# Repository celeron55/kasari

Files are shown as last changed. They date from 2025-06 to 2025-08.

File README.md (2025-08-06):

# Kasarisw: Spinning Robot with LIDAR Navigation

## Overview
This project features a spinning robot using a repurposed LDS02RR LIDAR (fixed
mount, fake encoder for max sampling) to enable autonomous navigation and
object following/wall avoidance. The robot spins its body (500-2000 RPM),
measures rotation via ADXL373 accelerometer, and achieves directional movement
through differential motor RPM modulation.

See `kasarisw/README.md` for information about the software.

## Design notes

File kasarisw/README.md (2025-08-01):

# Kasarisw: Spinning Robot with LIDAR Navigation

## Overview
This project features a spinning robot using a repurposed LDS02RR LIDAR (fixed
mount, fake encoder for max sampling) to enable autonomous navigation and
object following/wall avoidance. The robot spins its body (500-2000 RPM),
measures rotation via ADXL373 accelerometer, and achieves directional movement
through differential motor RPM modulation.

- **Firmware**: ESP32-based, handles sensors, motion planning, WiFi event streaming (binary over TCP).
- **Simulator**: PC GUI (egui) for log replay or virtual world simulation; visualizes LIDAR points, detections, behavior and collisions.
- **Shared Logic**: LIDAR/accel processing, binning (90 bins, 4° each), object detection (walls/objects via averages/dips).
- **Python GUI**: `event_monitor.py` for real-time monitoring, logging (JSON), controls over TCP.
- **Goals**: Compare real vs. simulated behavior; optimize non-standard LIDAR setup.

The robot maintains two rotations: physical (LIDAR orientation, integrated from
RPM) and virtual (stabilized relative to the world, limited by sensor
accuracy). In the simulator, the robot is rendered with its virtual rotation
fixed (pointing +X), keeping the world mostly static but adjusted for
measurement offsets/errors—useful for analyzing behavior. It produces event
logs over WiFi (captured via `event_monitor.py`), which can be replayed in the
simulator to compare real vs. simulated behavior, visualizing LIDAR points,
detections, and planner outputs.

## Simulator Architecture Notes
The system uses a MainLogic class shared between the embedded target and the
simulator for event processing and motion planning. In simulation mode (--sim),
SimEventSource owns the authoritative MainLogic to generate events (e.g.,
Lidar, Accelerometer, Planner) and drive physics. In replay mode (log file),
FileEventSource handles event sourcing (including synthetic injections like
--inject-autonomous) and uses a ReplayMirror (wrapping MainLogic) to process
events for consistent visualization. MyApp queries the EventSource trait for
logic data (e.g., detector, plans) uniformly, avoiding duplication. Flags like
--reverse-rotation are applied to each source's logic for RPM consistency.
--listen allows controlling the simulator using the same tools used to control
the robot over wifi.

## Project Structure
- `src/embedded.rs`: ESP32 firmware entrypoint.
- `src/sensors.rs`: Sensor tasks (LIDAR UART parsing, accel SPI, RC RMT).
- `src/shared/mod.rs`: Core logic (MainLogic, MotorModulator, event handling).
- `src/shared/algorithm.rs`: ObjectDetector (binning, RPM from accel, detection via window averages/large changes).
- `src/simulator/mod.rs`: Simulator entrypoint.
- `src/simulator/app.rs`: Egui app for visualization.
- `src/simulator/events.rs`: Event parsing from JSON logs.
- `src/simulator/physics.rs`: Virtual world raycasting, robot physics.
- `src/simulator/sources.rs`: Event sources (file replay or simulation).
- `tools/event_monitor.py`: Tkinter GUI for monitoring/controls/logging.
- `tools/download_events.py`: CLI for downloading events from robot's flash storage
- `tools/parse_events.py`: CLI binary event parser to JSON.
- `tools/combat_wizard.py`: Tkinter GUI for combat workflow. Combines event_monitor.py and download_events.py functionalities into one tool
- `rust-toolchain.toml`: Specifies ESP toolchain (channel: esp, target: xtensa-esp32-none-elf).
- `config.toml`: Cargo config with target rustflags, unstable build-std, aliases (build-pc, build-esp, run-esp).

## Key Algorithms
- **RPM from Accel**: `a_calibrated = accel_g - offset; omega = sqrt(|a| / r); rpm = (omega * 60) / (2π)` (r=0.0145m).
- **LIDAR Binning**: 90 bins; theta integrated from RPM/dt; distances binned with interpolation/fill.
- **Detection**: Window averages (5-15 bins); find min/max for wall/open; objects via large diffs/dips; fallback protrusion check.
- **Modulation**: Base RPM + amplitude * cos(theta - phase) for directional movement.
- **Autonomous**: Blend vectors: away from wall + toward open/object; clamp mag 0.5-1.0.

## Prerequisites
- Rust 1.88 (stable); project uses rust-toolchain.toml for ESP target.
- PC: No special setup.
- Embedded: Python 3 (tkinter for tools); install ESP32 toolchain:
  ```sh
  rm -rf ~/.rustup/toolchains/esp  # Clean install (optional)
  rustup override unset
  cargo install espup
  espup install
  cp $HOME/export-esp.sh .  # Copy to project root
  ```
- Hardware: ESP32, LDS02RR (RX only), ADXL373 (SPI), motors/ESCs (PWM), battery (ADC).

## Build/Run
### PC Simulator
```sh
cargo +stable build-pc  # Alias for cargo build --features pc
./target/debug/simulator [OPTIONS] [SOURCE]  # SOURCE: log file or --sim for virtual and --listen for listening to control tools
```
Options: --debug, --inject-autonomous, --lidar-distance-offset <MM>, --sim.

Profiling using flamegraph:
```sh
cargo +stable flamegraph -b simulator --features=pc -- --sim --headless --end-time 100
flamegraph --perfdata perf.data --image-width 4096
```

### Embedded Firmware
```sh
. export-esp.sh  # Source toolchain env
export SSID=... PASSWORD=...  # For STA WiFi
cargo build-esp  # Alias for cargo build --target xtensa-esp32-none-elf --features esp
cargo run-esp  # Alias for cargo run --target xtensa-esp32-none-elf --features esp --bin kasarisw (flash/run)
./monitor.sh  # Serial logs
```

## Monitoring/Control
- GUI: `python tools/event_monitor.py` (connect to 192.168.2.1:8080 AP or STA IP:8080).
  - Features: View sensors/planner, toggle modes (1=manual sliders, 2=autonomous), auto-log JSON.
- CLI Download: `python tools/download_events.py [IP:PORT]` (defaults to
  192.168.1.248:8081; downloads flash-stored events, splits into JSON logs).
- CLI: `nc IP 8080 | python tools/parse_events.py > log.json`.
- Events: Binary (tag XOR 0x5555 + payload) over TCP; JSON in logs.

## Hardware Pinout (ESP32)
- Motors: GPIO26/27 (PWM right/left).
- LIDAR: GPIO13 (encoder PWM), GPIO16 (UART RX).
- Accel: GPIO5 (CS), GPIO18 (SCLK), GPIO19 (MISO), GPIO23 (MOSI).
- RC: GPIO34 (RMT PWM in).
- Battery: GPIO39 (ADC).

## Dependencies (Cargo.toml)
- Shared: embassy-sync, ringbuffer, static_cell, arrayvec, num-traits, libm.
- Embedded: esp-hal, esp-wifi, esp-alloc, etc.
- Simulator: clap, eframe/egui_plot, serde_json.

## Event Format
- Lidar: [ts, d1..d4] (mm).
- Accel: [ts, ay, az] (G).
- Receiver: [ts, ch, pulse|null] (us).
- Vbat: [ts, voltage] (V).
- WifiControl: [ts, mode, r, m, t].
- Planner: [ts, rotation_speed, movement_x, movement_y, cw_x, cw_y, os_x, os_y, op_x, op_y, theta, rpm].

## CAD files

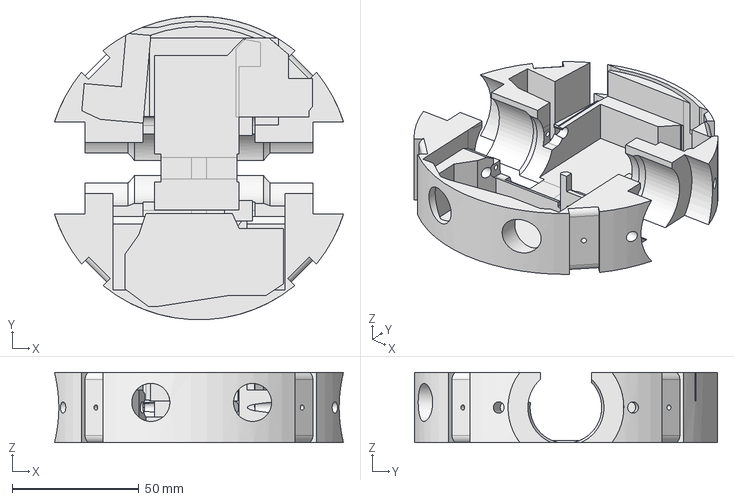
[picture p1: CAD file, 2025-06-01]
cad/kasari1.FCStd
113.9 x 119.5 x 27.6 mm

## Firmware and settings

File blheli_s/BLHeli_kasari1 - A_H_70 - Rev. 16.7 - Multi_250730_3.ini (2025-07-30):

[ESC0]
Eep_Name=kasari1.2
Eep_ESC_Layout=A_H_30
Eep_ESC_MCU=#BLHELI$EFM8B21#
Eep_ESC_Mode=2
Eep_FW_Main_Revision=16
Eep_FW_Sub_Revision=7
Eep_Layout_Revision=33
Eep_Pgm_Startup_Pwr=10
Eep_Pgm_Direction=3
Eep_Enable_TX_Setup=1
Eep_Pgm_Comm_Timing=3
Eep_Pgm_Ppm_Min_Throttle=37
Eep_Pgm_Ppm_Max_Throttle=208
Eep_Pgm_Beep_Strength=24
Eep_Pgm_Beacon_Strength=80
Eep_Pgm_Beacon_Delay=4
Eep_Pgm_Demag_Comp=2
Eep_Pgm_Ppm_Center_Throttle=122
Eep_Pgm_Temp_Prot_Enable=3
Eep_Pgm_Enable_Power_Prot=0
Eep_Pgm_Brake_On_Stop=0
Eep_Pgm_LED_Control=0

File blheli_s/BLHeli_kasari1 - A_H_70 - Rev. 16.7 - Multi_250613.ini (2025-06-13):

[ESC0]
Eep_Name=kasari1
Eep_ESC_Layout=A_H_70
Eep_ESC_MCU=#BLHELI$EFM8B21#
Eep_ESC_Mode=2
Eep_FW_Main_Revision=16
Eep_FW_Sub_Revision=7
Eep_Layout_Revision=33
Eep_Pgm_Startup_Pwr=9
Eep_Pgm_Direction=3
Eep_Enable_TX_Setup=1
Eep_Pgm_Comm_Timing=3
Eep_Pgm_Ppm_Min_Throttle=37
Eep_Pgm_Ppm_Max_Throttle=208
Eep_Pgm_Beep_Strength=21
Eep_Pgm_Beacon_Strength=80
Eep_Pgm_Beacon_Delay=4
Eep_Pgm_Demag_Comp=2
Eep_Pgm_Ppm_Center_Throttle=122
Eep_Pgm_Temp_Prot_Enable=7
Eep_Pgm_Enable_Power_Prot=0
Eep_Pgm_Brake_On_Stop=0
Eep_Pgm_LED_Control=0

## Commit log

2025-05-28 Don't print angle or speed as those are useless without the original spinning mechanism
2025-05-28 Update control board length
    [kasari1.FCStd]
2025-05-29 Add steel rods and tweak steel ring shape
    [kasari1.FCStd]
2025-05-29 Steel rods 5->6mm
    [kasari1.FCStd]
2025-05-29 Swap control board and accelerometer model
    [kasari1.FCStd]
2025-05-31 Inner body design WIP
    [kasari1.FCStd]
2025-05-31 Inner body: Control board and ESC pockets; ESC placement change
    [kasari1.FCStd]
2025-05-31 Inner body: Motor mount WIP
    [kasari1.FCStd]
2025-05-31 Inner body WIP
    [kasari1.FCStd]
2025-05-31 Motor 45° rotation WIP
    [kasari1.FCStd]
2025-05-31 Motor 45° rotation: Rotate receiver 5° to fit
    [kasari1.FCStd]
2025-05-31 Inner body is OK for printing
    [kasari1.FCStd]
2025-06-01 Inner body improvements
    [kasari1.FCStd]
2025-06-01 Inner body: Add support for battery inner edge; Move receiver 0.5mm outwards to give some thread to the adjacent motor screw
    [kasari1.FCStd]
2025-06-01 Inner body: Add motor screw access holes
    [kasari1.FCStd]
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2025-06-02 Inner body: Make room for ESC power supply connectors
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2025-06-07 Read RC receiver PWM using the RMT peripheral
2025-06-13 Correct direct ESC control; however channelN.set_duty()'s u8 argument is a bit too coarse
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2025-06-22 Move receiver -> motor control conversion to mod kasari
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2025-07-06 Respond to client with device status instead of fetching a page from another server
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2025-07-10 Modularize parse_event and add support for accelerometer Z
2025-07-10 src/sensors.rs: Validate lidar angle before multiplying to avoid overflow panic
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2025-07-11 Disable lidar_writer task and print received bytes on the TCP socket
2025-07-11 Flush TCP socket less often to get enough throughput
2025-07-11 tools/parse_events.py: Print skipped bytes
2025-07-11 Better tags encoding for events for avoiding desync
    [shared.rs]
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2025-07-13 tools/simulator.py: Leave lidar points visible for 500ms instead of 100ms
2025-07-13 Read lidar data at shorter interval to get more accurate lidar timestamps
2025-07-13 tools/simulator.py: Drop lidar timestamp smoothing; add accelerometer lowpass
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2025-07-17 Read UART2 in interrupt to timestamp lidar data accurately
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2025-07-17 Generate LIDAR encoder signal using LEDC to make LIDAR readings consistent
2025-07-17 Fix LIDAR encoder signal generation
2025-07-17 tools/simulator.py: Add event stepping mode with hilighted lidar points of the current event
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2025-07-17 tools/simulator.py: Drop old lidar points at 100ms and fix slow and pause modes
2025-07-17 tools/simulator.py: Dynamic fade time; calculate angle between 4 samples in lidar event properly
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2025-07-17 Increase LIDAR encoder encoder rate. This smooths out the LIDAR message interval as the UART baud is exhausted, probably due to buffering internal to the LIDAR itself
2025-07-18 Increase LIDAR encoder rate from 60 Hz to 83 Hz to minimize buffering delays and maximize the number of samples
2025-07-18 Decrease LIDAR encoder rate from 83 to 80 Hz to make it produce valid measurements
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2025-07-18 tools/algorithm.py: Limit number of points to 200 which is enough for >800rpm operation
2025-07-19 Rust version of the simulator and algorithm work now on PC. It builds but doesn't work on ESP32
2025-07-19 Optimize algorithm. Builds and works on PC, not on ESP32
2025-07-19 Algorithm builds on ESP32 but panics at memory allocation
2025-07-19 Change LIDAR_EVENT_QUEUE to be a ConstGenericRingBuffer instead of VecDeque to put a cap on its size and avoid memory allocations
2025-07-19 simulator: Keep track of theta offset and offset displayed Planner event angles
2025-07-19 main.rs: We're fine with a 500ms old motor control plan
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2025-07-19 ObjectDetector: Don't alter last_ts and theta based on Accelerometer events
2025-07-19 MainLogic: Autonomous operation: Don't drive motors if battery voltage is low
2025-07-19 550rpm should be good enough for moving around
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2025-07-20 Read LIDAR packets from UART in batches to ease CPU usage
2025-07-20 Log LIDAR at 100 packet interval instead of 20
2025-07-20 Always shut down motor controllers when battery is not present
2025-07-20 Make sure the LIDAR not seeing anything is interpreted correctly both in autonomous operation and when playing back old or new logs
2025-07-20 simulator: Choose clearer colors and hide motor dots and vectors
2025-07-21 algorithm: Fill in more than one bin if rotating so fast that the LIDAR samples would skip some otherwise
2025-07-22 Correct event-internal LIDAR timing
2025-07-22 Arena size, robot position and robot velocity detection
2025-07-22 Improve autonomous_update: Alternate between arena center and object, and cancel out unwanted velocity
2025-07-22 Fix ESP32 build
2025-07-22 MotorModulator: Allow initial jump in RPM within RPM_INITIAL_JUMP
2025-07-22 Support negative RPM in LIDAR scanning, object detection and xy movement (tested in simulator; ESP32 target at least compiles)
2025-07-23 Detect and properly control a flipped robot (tested only on simulator)
    [embedded.rs]
2025-07-23 autonomous_update: Reverse rotation every 5 seconds when stopped (<150rpm)
2025-07-23 Get rid of dual MainLogic in --sim mode. This fixes most angle offset issues when simulating
    [embedded.rs]
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2025-07-23 Report LIDAR skipped/valid bytes. Currently there seem to be about 10100 skipped and 0 valid per second
    [embedded.rs]
2025-07-24 Fix LIDAR packet stream parsing
    [embedded.rs]
2025-07-24 Close log download socket before erasing flash so that the download tool can exit faster
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2025-07-24 Much heavier filtering on Z acceleration to stabilize flipped status
2025-07-24 Fix motor modulation polarity
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2025-07-24 SimEventSource: Give more time and smaller noise for Z to calibrate
2025-07-24 Flip detector WIP. Doesn't match in output to tools/analyze_flip.py, even though it tries to
    [embedded.rs]
2025-07-24 Control GPIO2 LED to indicate state of accelerometer
2025-07-25 algorithm.rs: Calibrate accelerometer Y axis based on 50 samples instead of 10. This maybe helps a bit, maybe not
2025-07-25 Replace accelerometer based flip detection with velocity based flip detection. This doesn't work properly yet. Velocity detection needs to more stable
    [embedded.rs]
2025-07-25 Flip detection via movement detection. Doesn't work very well
    [embedded.rs]
2025-07-25 MainLogic: Last iteration of velocity monitoring based freeform angle correction
2025-07-25 Commit for testing: 0/180 angular correction based on time based statistics about walls and velocity
2025-07-25 src/shared/algorithm.rs: Average bins like it was done some time back. Hopefully this helps the lidar plot a bit
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2025-07-25 simulator: Add LIDAR noise
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2025-07-28 cad: Wheel support: Shorten by 0.5mm
2025-07-28 cad: Lift control board pocket by 1mm to reinforce right motor mount screw hole; enlarge motor screw holes from 2.1mm to 2.2mm diameter to make splitting less likely; shrink motor pocket radius by 0.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
2025-07-28 cad: LIDAR holes: Move sensor hole 1mm inwards; USB slot in inner body; Fill in useless space next to power switch (where the balancing connector likes to get stuck); Give more length to ring screw h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
2025-07-28 cad: Make cover attachment holes thicker on the underside. Now the holes are about 2mm thick from the top and 3mm thick from the bottom, up to 19.5mm in height (hole is at 15.0mm)
2025-07-28 Add default URLs in dropdown (Combobox), switch default to 192.168.2.1:8080 which is the AP (set static IP 192.168.2.2 on device) and don't connect on startup
2025-07-29 cad: Add a bit more material between motors and battery; Adjust right ESC wiring route
2025-07-29 cad: Enlarge motor hole diameter back from 14.8 to 15.0mm; clear space around motors in a way where it won't matter if bottom layers warp 2mm upwards or really any vertical warping happens; change mo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
2025-07-30 Increase RC Receiver timeout from 1s to 5s to make sure robot stays spinning in case of bursts of bad reception, which sometimes happen
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2025-07-30 Do motor controller reset if robot fails to spin at least 25% of target rpm for more than 2 seconds, with 10 second cooldown
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2025-07-31 New panic handler: Record panic to flash, blink LED 5 times for 5 seconds while printing panic message on UART. Serve panic message on port 8081. Add support to tools/download_events.py to print out 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
2025-07-31 Fix event log serialization into flash (duplicate events)
    [embedded.rs]
2025-07-31 Rework motor controller reset to not spam Planner events and be better structured
2025-07-31 Speed up ESC reset process a bit (10 -> 6s interval, 2.0 -> 1.5s reset time
2025-07-31 Fix accelerometer radius now that new capacitors were added on the LIDAR side of the robot. This was based on log/kasarisw_2025-07-31_211930_6.log
